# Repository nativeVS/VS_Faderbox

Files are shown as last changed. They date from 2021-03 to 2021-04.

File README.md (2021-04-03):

# VS_Faderbox

A small Teensy based MIDI Faderbox;  
built around [ttapa's Control Surface Library](https://github.com/tttapa/Control-Surface)

## Overview

This project was born out of the desire of having a small MIDI fader controller to ease in the work with orchestral libraries.
  
The MIDI Channel and Fader Assignment can be changed via MIDI System Exclusive messages (described in more detail below).
I have written a (low quality) program that lets you quickly generate a SysEx file should you wish to avoid doing it the fun way (link below or [here](https://github.com/nativeVS/VS_SysEx_Generator)).
In addition new for version 5 there is an editor software (link below or [here](https://github.com/nativeVS/VS_Faderbox_Editor)) which is a simple Electron built application using WebMIDI, heavily inspired by the nakedboards editor.
  
On the PCB there is the provision to add 4 extra potentiometers with pull down resistors (eg. for external expression pedals or similar);
more info in the DIY Notes section.
  
### Links

* [ttapa's Control Surface Library](https://github.com/tttapa/Control-Surface)
* [SysEx Generator](https://github.com/nativeVS/VS_SysEx_Generator)
* [Editor](https://github.com/nativeVS/VS_Faderbox_Editor)
* [nakedboards](https://nakedboards.org/)

#### Contents of the sub-directories are as follows
* VS_Faderbox - Teensyduino Sketch
* CAD Files - Full KiCad Project directory for PCB & AutoCAD files for physical box.

## SysEx Format

Channel and Fader Reassignment SysEx Format:
```
F0 [id] [id] [id] [dI] [s1] [s2] [cc] [f0] [f1] [f2] [f3] xx F7
```
With manufacturer ID (`[id] [id] [id]`), device id (`[dI]`) and sub ids #1 & #2 (`[s1] [s2]` which correspond to model number and version number for this device);
the Checksum (xx) includes the entire SysEx message (i.e. starting with the device ID) and should add up to `FF` with all preceding elements.
The Device ID is in the normal version fixed to 0x01.
  
Thus the SysEx string for the default assignment is as follows:
```
F0 00 21 57 01 02 05 01 01 0B 15 14 40 F7
```
To request the current Channel and Fader assignment the box responds to the following SysEx:
```
F0 [id] [id] [id] [dI] [s1] [s2] 0x11 xx F7
```
This will trigger the following response:
```
F0 [id] [id] [id] [dI] 0x00 [s2] [cc] [f0] [f1] [f2] [f3] xx F7
```

It will respond to the standard SysEx ID Requests:
```
F0 7E 01 06 01 F7 (device id 01) or
F0 7E 7F 06 01 F7 (ignore device id)
```
SysEx ID Request Reply:
```
F0 7E 01 06 02 [id] [id] [id] 01 01 00 02 00 00 00 05 F7
                              |   | |   | |---------- Software Version No: v5
                              |   | |---- Model Number: 00 02
                              |---- Family Code: 01 01
```
  
## DIY Notes

todo: add more detail
  
This sketch was designed for a Teensy LC and might not work correctly on lower spec boards.
  
#### Expansion Notes

There is provision for a 6 pin header on the PCB, which connects to V+ (3V3), GND and Analogue Inputs A4, A5, A6 & A7.  

As a general note, I would recommend using Mappingfunctions for any external potentiometers (many expression pedals not having the full resistor range available) as can be found in the [following example](https://github.com/tttapa/Control-Surface/blob/master/examples/1.%20MIDI%20Output/1.%20Potentiometers%20%26%20Faders/CCPotentiometer-Map/CCPotentiometer-Map.ino) part of the Control Surface Library.  

If you are unsure how the general sketch works, I would highly recommend hardcoding MIDI CC and Channel values for any edits.

nativeVS - 2021

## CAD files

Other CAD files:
CAD Files/AutoCAD/box_idea_1-v2.dwg
CAD Files/AutoCAD/box_idea_1-v1.dwg

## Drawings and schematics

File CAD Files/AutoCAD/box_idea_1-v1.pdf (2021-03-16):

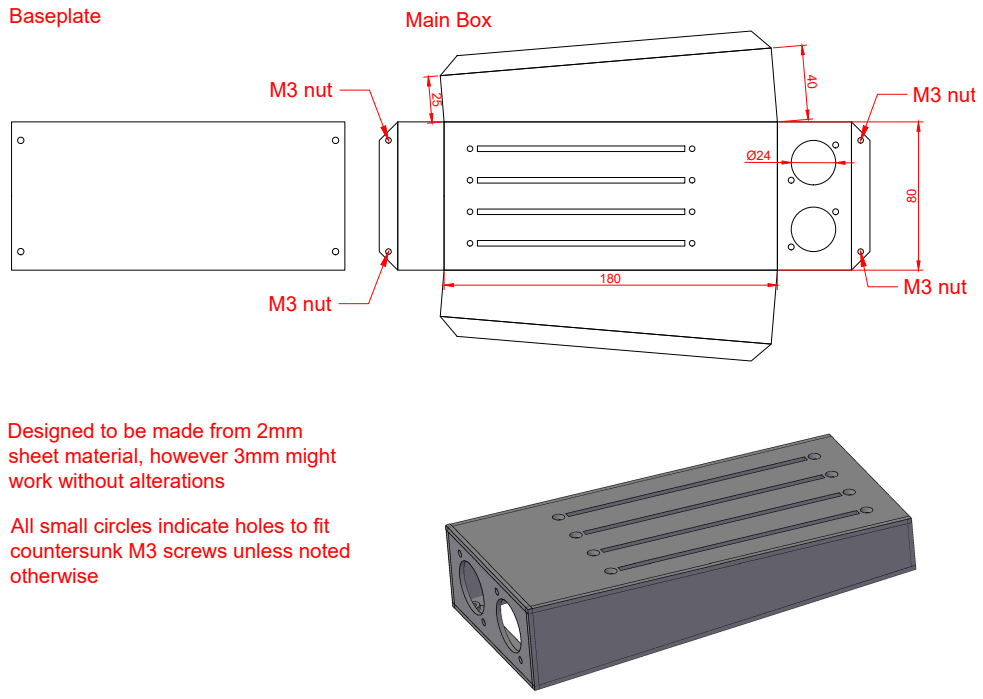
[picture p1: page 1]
Designed to be made from 2mm sheet material, however 3mm might work without alterations Baseplate; M3 nut All small circles indicate holes to fit countersunk M3 screws unless noted otherwise; Main Box; 40 M3 nut 25 M3 nut M3 nut

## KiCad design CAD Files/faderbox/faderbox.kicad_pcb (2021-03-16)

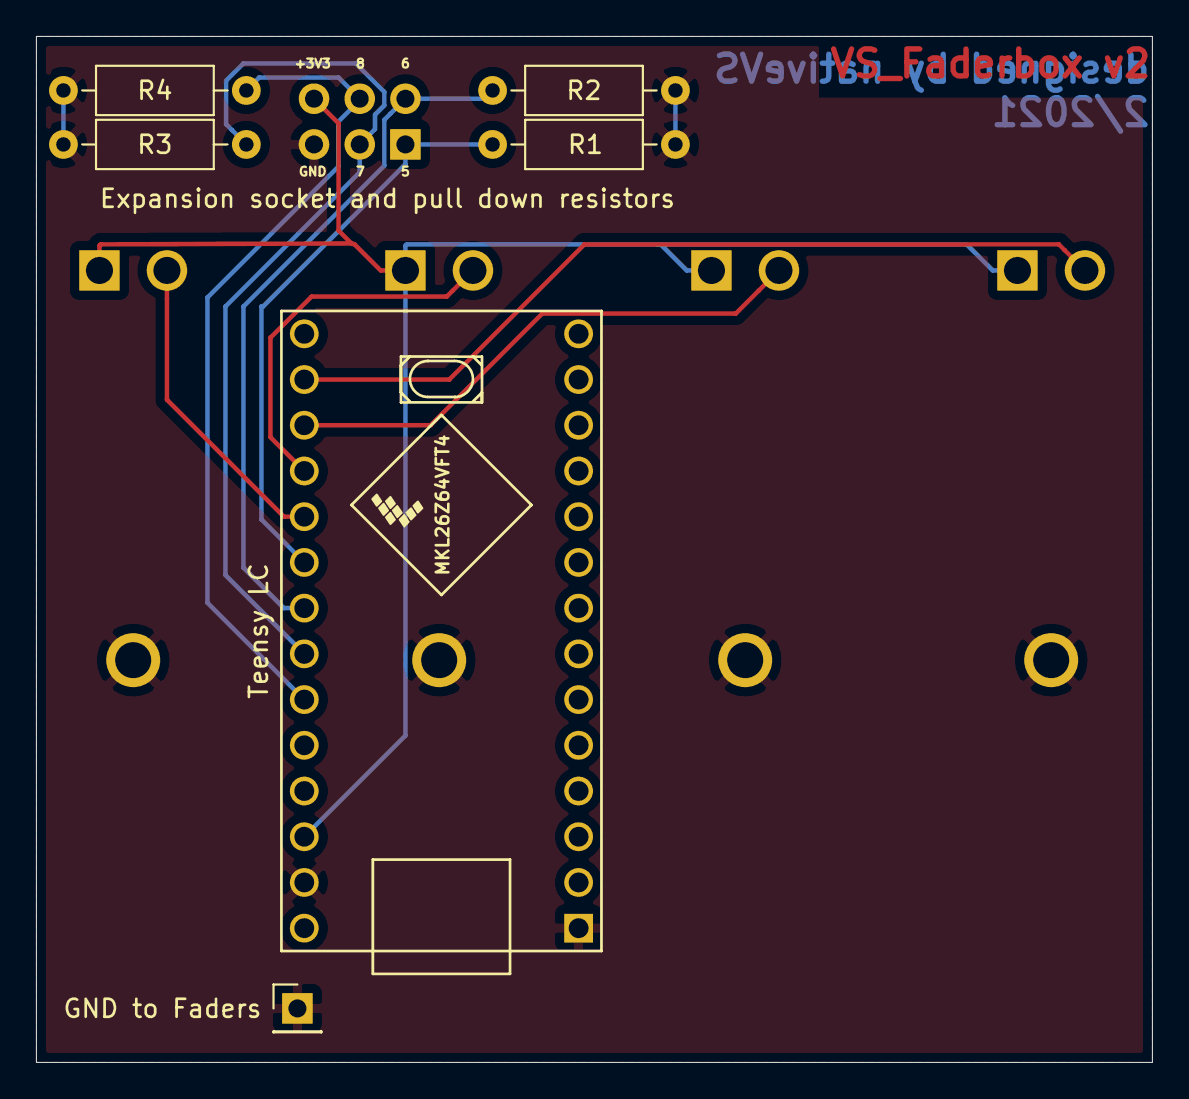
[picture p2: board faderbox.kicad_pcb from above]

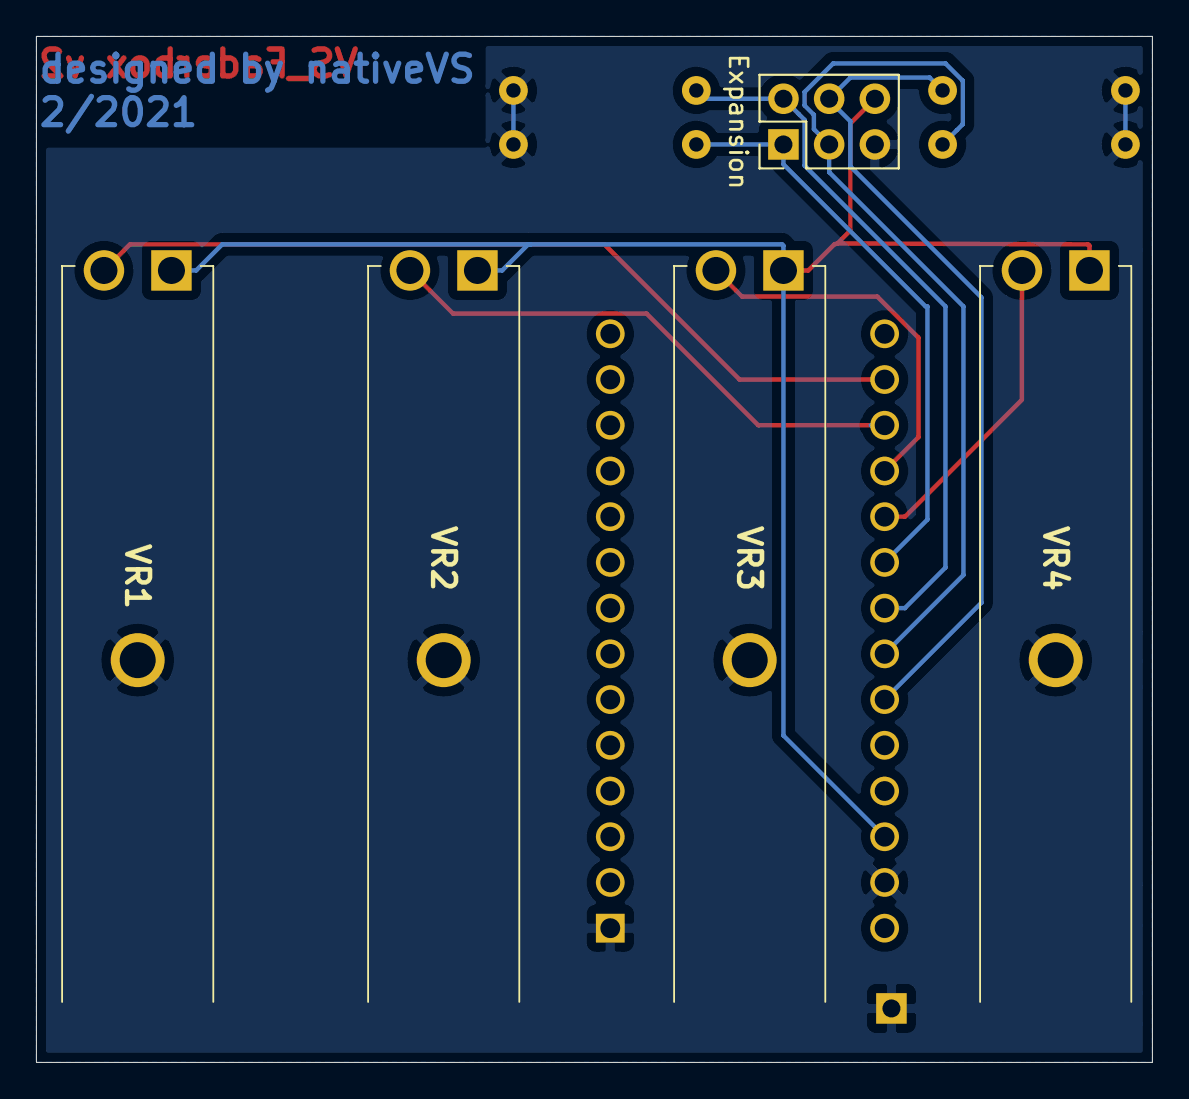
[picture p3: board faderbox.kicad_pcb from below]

Board: 2 copper layers, 62.0 x 57.0 mm, 11 parts (5 on the bottom side), 10 nets.

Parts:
Expansion: exp; PinHeader_2x03_P2.54mm_Vertical
GND to Faders: GND to Faders; PinHeader_1x01_P2.54mm_Vertical
R1, R2, R3, R4: 1M; R_Axial_DIN0207_L6.3mm_D2.5mm_P10.16mm_Horizontal
Teensy LC: Teensy-LC; Teensy_LC-reduced
VR1, VR2, VR3, VR4: 10k; RSA0N11S9A0K-half

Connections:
GND: Expansion.5, GND to Faders.1, R1.1, R2.1, R3.1, R4.1, Teensy LC.1, Teensy LC.32, VR1.MH2, VR2.MH2, VR3.MH2, VR4.MH2
unnamed: Expansion.1, R1.2, Teensy LC.25
unnamed: Expansion.2, R2.2, Teensy LC.26
unnamed: Expansion.3, R3.2, Teensy LC.27
unnamed: Expansion.4, R4.2, Teensy LC.28
unnamed: Expansion.6, Teensy LC.31, VR1.1, VR2.1, VR3.1, VR4.1
unnamed: Teensy LC.21, VR1.2
unnamed: Teensy LC.22, VR2.2
unnamed: Teensy LC.23, VR3.2
unnamed: Teensy LC.24, VR4.2

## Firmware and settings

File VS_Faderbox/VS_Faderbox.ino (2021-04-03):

//
// VS_Faderbox
// 4 Fader Midi Controller
//
// Please reuse as much as you please, as I did creating this in the first place.
// This was originally written for the Teensy LC using tttapa's Control Surface Library
// https://github.com/tttapa/Control-Surface
// 
// nativeVS - 2021
//

//
// SysEx Specification:
//
// Channel and Fader Reassignment SysEx Format:
// F0 [id] [id] [id] [dI] [s1] [s2] [cc] [f0] [f1] [f2] [f3] xx F7
// with manufacturer ID (00 21 57), device id (01) and sub ids #1 & #2 (model number [02], version number [05] respectively);
// checksum includes manufacturer id
// in true unidirectional SysEx fashion, there is no aknowledgement of succesful receipt beyond a quick flash of the Teensy LED.
//
// Channel and Fader Reassignment SysEx Request:
// F0 [id] [id] [id] [dI] [s1] [s2] 0x11 xx F7
// Responds with following string:
// F0 [id] [id] [id] [dI] 0x00 [s2] [cc] [f0] [f1] [f2] [f3] xx F7
//
// Responds to SysEx ID Requests:
// F0 7E 01 06 01 F7 (device id 01) or
// F0 7E 7F 06 01 F7 (ignore device id 7F)
// SysEx Reply:
// F0 7E 01 06 02 [id] [id] [id] 01 01 00 02 00 00 00 05 F7
//                               |   | |   | |---------- Software Version No: v5
//                               |   | |---- Model Number: 00 02 (Teensy version)
//                               |---- Family Code: 01 01 (USB MIDI Controller)
//
// when reusing any of this source code please refrain from using my SysEx Manufacturer ID;
// please make sure to use the non-commercial ID (0x7D) or your own instead.
//

#include <Control_Surface.h>
#include <EEPROM.h>

USBMIDI_Interface midi;

constexpr byte deviceID{ 0x01 };
constexpr byte modelNumber[2]{ 0x00, 0x02 };
constexpr byte softwareVersion[4]{ 0x00, 0x00, 0x00, 0x05 };
constexpr byte manufacturerID[3]{ 0x00, 0x21, 0x57 };
constexpr byte requestCode{ 0x11 };
constexpr byte transmitCode{ 0x00 };

constexpr int sysExLength{ 14 };
constexpr int dataStart{ 7 };

constexpr byte defaultSysEx[sysExLength]{ 0xf0,             //Start of SysEx
  manufacturerID[0], manufacturerID[1], manufacturerID[2],  //Manufacturer ID
  deviceID, modelNumber[1], softwareVersion[3],             //Device & Sub IDs
  0x01, 0x01, 0x0b, 0x15, 0x14,                             //Start of Data: Default Channel & Fader assignment
  0x4a, 0xf7};                                              //Checksum and end of SysEx


byte MIDIchannel = EEPROM.read(0);

byte ccno_fader_0 = EEPROM.read(1);
byte ccno_fader_1 = EEPROM.read(2);
byte ccno_fader_2 = EEPROM.read(3);
byte ccno_fader_3 = EEPROM.read(4);

byte sysexIDreply[17]{0xf0, 0x7e, 0x01, 0x06, 0x02,         //Start of SysEx ID Reply as defined by MMA
  manufacturerID[0], manufacturerID[1], manufacturerID[2],  //Manufacturer ID
  0x01, 0x01,                                               //Family Code
  modelNumber[0], modelNumber[1],                           //Model Number
  softwareVersion[0], softwareVersion[1],
  softwareVersion[2], softwareVersion[3],                   //Software Version
  0xf7};                                                    //end of SysEx ID Reply



class AddressablePot : public Bankable::MIDIFilteredAnalog<Bankable::SingleAddressMultipleBanks<2>, ContinuousCCSender> {
  public:
    AddressablePot(const Array<OutputBankableMIDIAddress, 2> &banks, pin_t pin, MIDIAddress address)
        : Bankable::MIDIFilteredAnalog<Bankable::SingleAddressMultipleBanks<2>, ContinuousCCSender>({banks, address}, pin, {}) {}
};

Bank<16> channelBank(1);
Bank<128> addressBank_0(1);
Bank<128> addressBank_1(1);
Bank<128> addressBank_2(1);
Bank<128> addressBank_3(1);

AddressablePot faders[] = {
  {{{{channelBank, BankType::CHANGE_CHANNEL}, {addressBank_0, BankType::CHANGE_ADDRESS}}}, A0, {0x00, CHANNEL_1}},
  {{{{channelBank, BankType::CHANGE_CHANNEL}, {addressBank_1, BankType::CHANGE_ADDRESS}}}, A1, {0x00, CHANNEL_1}},
  {{{{channelBank, BankType::CHANGE_CHANNEL}, {addressBank_2, BankType::CHANGE_ADDRESS}}}, A2, {0x00, CHANNEL_1}},
  {{{{channelBank, BankType::CHANGE_CHANNEL}, {addressBank_3, BankType::CHANGE_ADDRESS}}}, A3, {0x00, CHANNEL_1}},
};

void readfromEEPROM(){
  
  MIDIchannel = EEPROM.read(0);
  channelBank.select(MIDIchannel - 1);

  ccno_fader_0 = EEPROM.read(1);
  ccno_fader_1 = EEPROM.read(2);
  ccno_fader_2 = EEPROM.read(3);
  ccno_fader_3 = EEPROM.read(4);
  addressBank_0.select(ccno_fader_0);
  addressBank_1.select(ccno_fader_1);
  addressBank_2.select(ccno_fader_2);
  addressBank_3.select(ccno_fader_3);
}

struct incomingSysEx : MIDI_Callbacks {
  public:
    void onSysExMessage(Parsing_MIDI_Interface &midi) override {
      SysExMessage sysex = midi.getSysExMessage();
      if (sysex.data[0] == 0xf0 // channel and fader reassignment message
      && sysex.data[1] == defaultSysEx[1] && sysex.data[2] == defaultSysEx[2] && sysex.data[3] == defaultSysEx[3] // Manufacturer ID
      && sysex.data[5] == defaultSysEx[5] && sysex.data[6] == defaultSysEx[6] // sub IDs
      && sysex.data[13] == 0xf7){
        byte checksm = sysex.data[12];
        for (int i=1; i<12; i++){
          checksm += sysex.data[i];
        }
        if (checksm == 0xff){
          for (int i = dataStart; i < (sysExLength - 2); i++){
             EEPROM.write(i - dataStart, sysex.data[i]);
           }
          readfromEEPROM(); // update midi assignments
          // Blink LED when ready
          digitalWrite(13, HIGH);
          delay(500);
          digitalWrite(13, LOW);
        }
      }
      if (sysex.data[0] == 0xf0 // ID Request
      && sysex.data[1] == 0x7e && (sysex.data[2] == 0x7f || sysex.data[2] == deviceID)
      && sysex.data[3] == 0x06 && sysex.data[4] == 0x01
      && sysex.data[5] == 0xf7){
        delay(50);
        midi.send(sysexIDreply);
      }
      if (sysex.data[0] == 0xf0 // request current channel and fader assignment
      && sysex.data[1] == defaultSysEx[1] && sysex.data[2] == defaultSysEx[2] && sysex.data[3] == defaultSysEx[3] // Manufacturer ID
      && sysex.data[5] == defaultSysEx[5] && sysex.data[6] == defaultSysEx[6] // sub IDs
      && sysex.data[7] == requestCode
      && sysex.data[9] == 0xf7){
        byte checksm = sysex.data[8];
        for (int i=1; i<8; i++){
          checksm += sysex.data[i];
        }
        if (checksm == 0xff){
          byte sysExReply[sysExLength]{};
          std::copy(std::begin(defaultSysEx), std::end(defaultSysEx), std::begin(sysExReply));
          sysExReply[5] = transmitCode;
          for (int i = dataStart; i < (sysExLength - 2); i++){
            sysExReply[i] = EEPROM.read(i - dataStart);
          }
          byte notChecksm{};
          for (int i = 1; i < (sysExLength - 2); i++){
            notChecksm += sysExReply[i];
          }
          sysExReply[sysExLength - 2] = (0xff - notChecksm);
          delay(50);
          midi.send(sysExReply);
        }
      }
    }
} callback = {};

void setup() {
  pinMode(13, OUTPUT); //LED
  
  Control_Surface.begin();

  midi.begin();
  midi.setCallbacks(callback);

  readfromEEPROM();

  //Blink LED when ready
  digitalWrite(13, HIGH);
  delay(1000);
  digitalWrite(13, LOW);
}

void loop() {
  Control_Surface.loop();

  midi.update();
}
